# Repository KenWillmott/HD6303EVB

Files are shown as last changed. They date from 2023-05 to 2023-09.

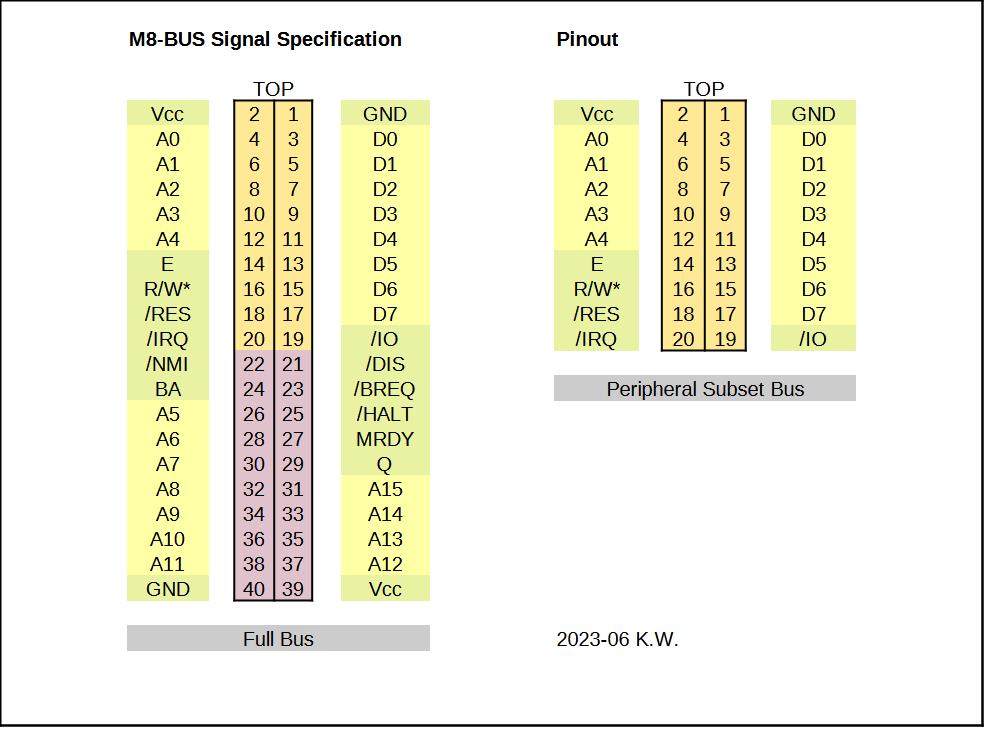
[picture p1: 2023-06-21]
expansion-pinout-final.jpg

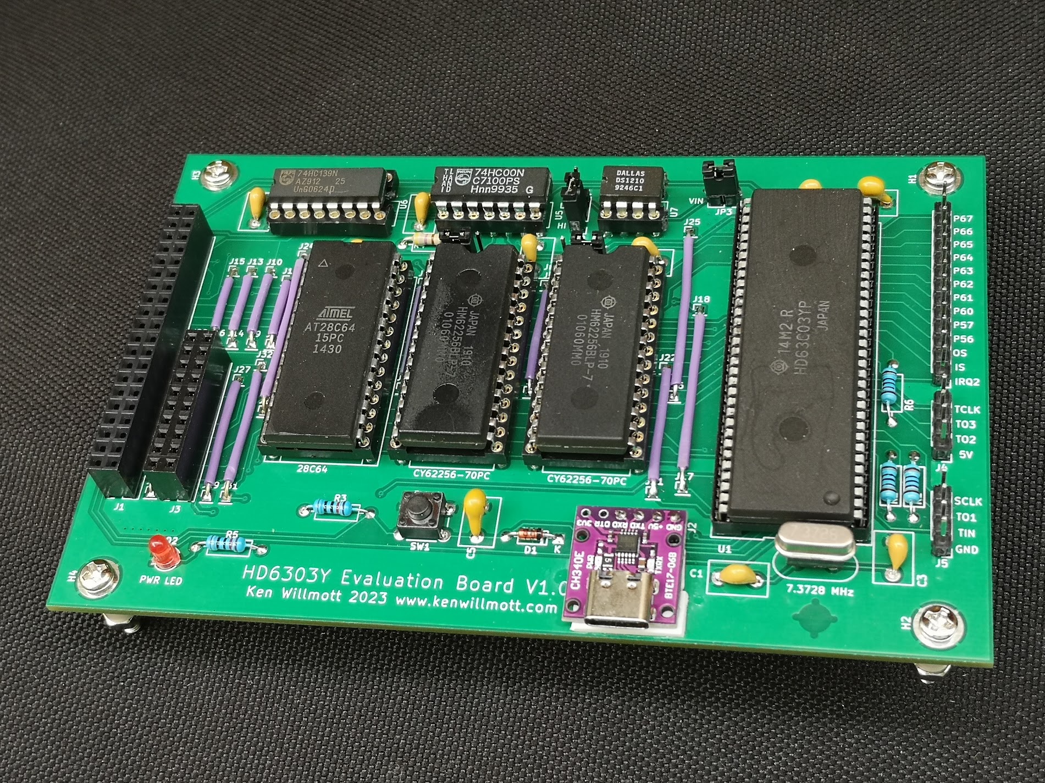
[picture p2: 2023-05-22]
HDEVB-SN002.jpg

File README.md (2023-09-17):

# HD6303EVB
# Hitachi HD63C03YP Evaluation Board

The HD63C03YP is a Hitachi MCU that combines a Motorola MC6803 code compatible processor, with on chip peripherals such as UART, parallel I/O, and hardware timers and counters. The MC6803 is code compatible with the MC6801, so development tools such as an assembler can be used to produce code for it. Also, existing software written for the MC6801/6803 should run on it, with few or no modifications.

The historical background is that Hitachi obtained a licence from Motorola to produce many of the devices in Motorola's 8 bit MCU catalog, which they implemented in an improved CMOS process. Many of the devices are pin compatible drop in replacements for the Motorola parts. But Hitachi also added new parts, and enhanced some of them with both documented and undocumented improvements.

The board consists of a 64 pin DIP HD63C03YP MCU, an 8k EEPROM, an external bus interface, I/O pins, and 64k SRAM. It can be interfaced from the on board serial port, running at 115200 baud and some slower baud rates. More hardware details can be found in the Wiki - https://github.com/KenWillmott/HD6303EVB/wiki.

The project is in the extreme beta stage, at the moment four working boards exist. The first and current board is designated V1.0. Some peripheral boards to plug into the expansion bus connectors, are in development. The Game Board is completed, see https://github.com/KenWillmott/M8-Game-Board/wiki

The provided ROM monitor program Kbug6303, can be written to the 8k EEPROM. Once it is installed, it is possible to perform firmware updates in place, by changing the write protect jumper on the board, and running software to copy the code from RAM to the EEPROM.

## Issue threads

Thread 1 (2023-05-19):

serial interface pin spacing

KenWillmott, 2023-05-19:
The pin header through holes are on 2mm centres and so don't align with the 2.54mm centres on a typical pin header. Fix in next revision.

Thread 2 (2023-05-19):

bus connector spacing

KenWillmott, 2023-05-19:
The spacing between adjacent bus connectors is too small. The right angle connectors that are planned for the peripheral cards require a wider gap. The dimension needs to be estimated.

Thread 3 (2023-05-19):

power supply connections

KenWillmott, 2023-05-19:
Currently the power comes from the USB-serial adapter. For more flexibility, a dedicated power supply connector and a jumper to select either it, or the USB power should be added.

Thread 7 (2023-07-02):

reset fan out

KenWillmott, 2023-07-02:
Several devices utilize the RESET line, connected to an RC circuit. This means devices come out of reset at different times because the inputs have different logic thresholds. It may be better to buffer the reset signal so that all devices are reset simultaneously.

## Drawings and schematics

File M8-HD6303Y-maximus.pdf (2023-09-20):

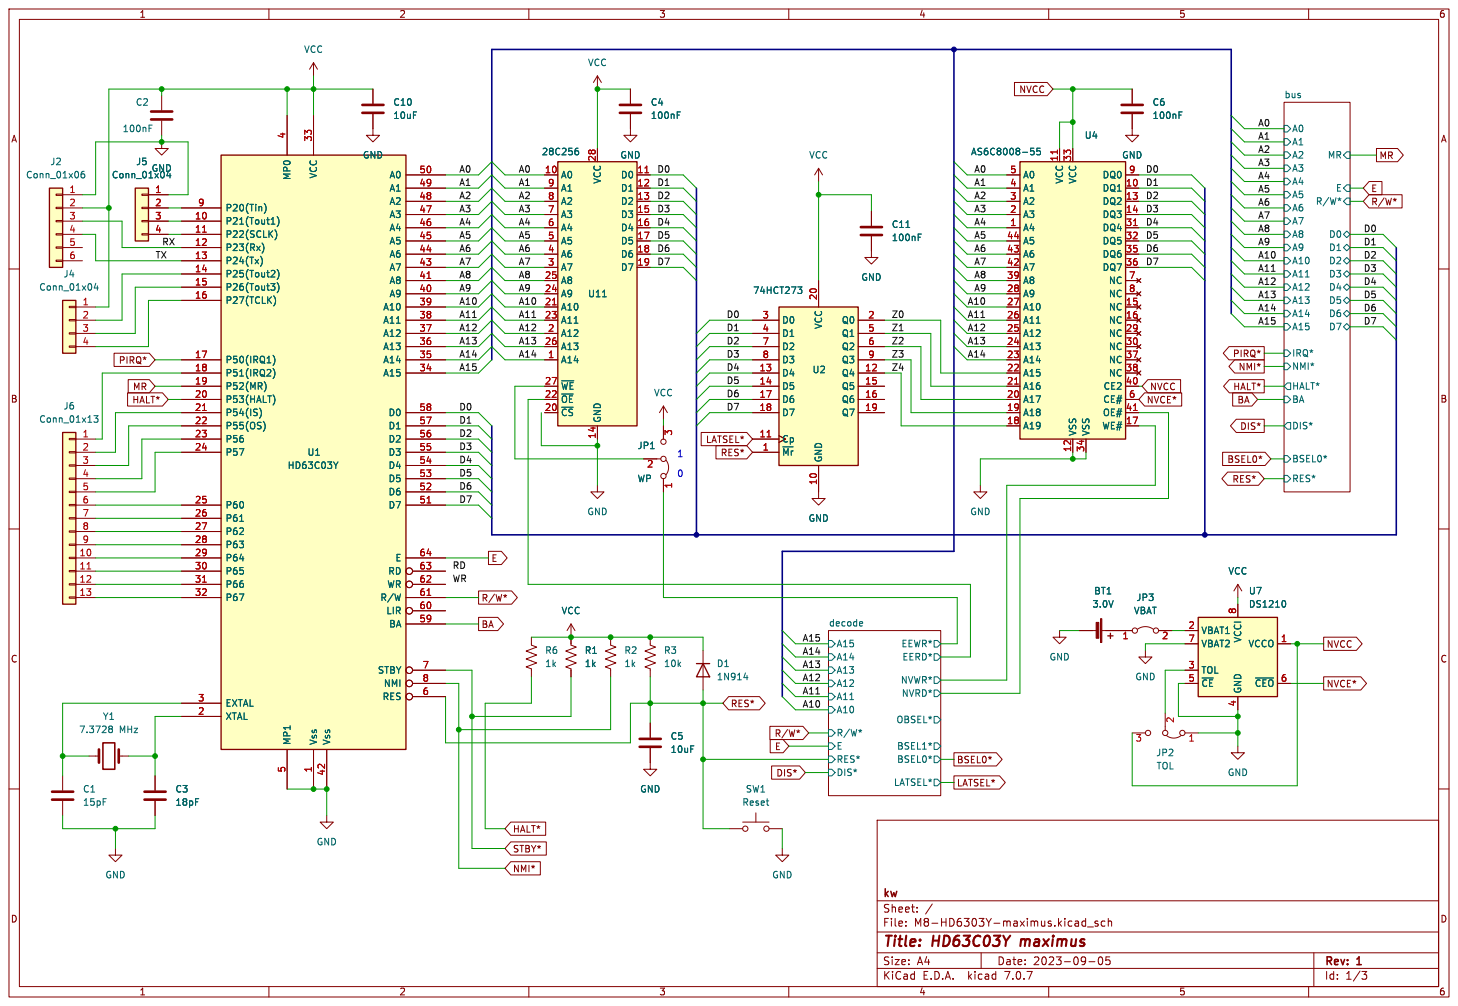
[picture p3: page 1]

File: M8-HD6303Y-maximus.kicad_sch Sheet: / kw

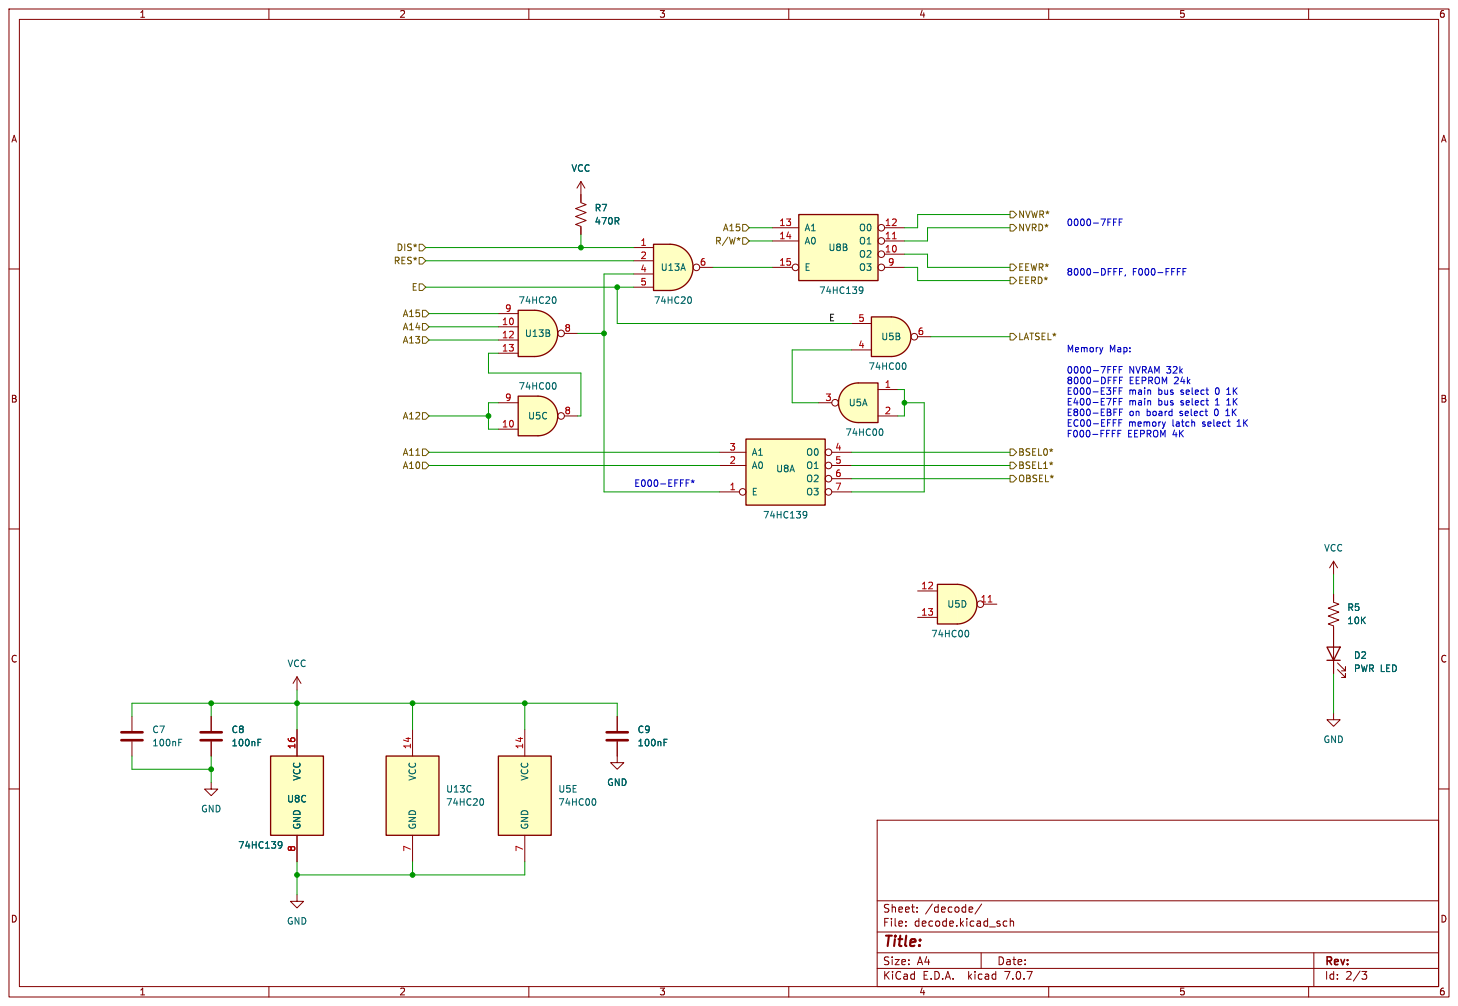
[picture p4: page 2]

Id: 2/3 Title: File: decode.kicad_sch Sheet: /decode/ VCC 14 GND

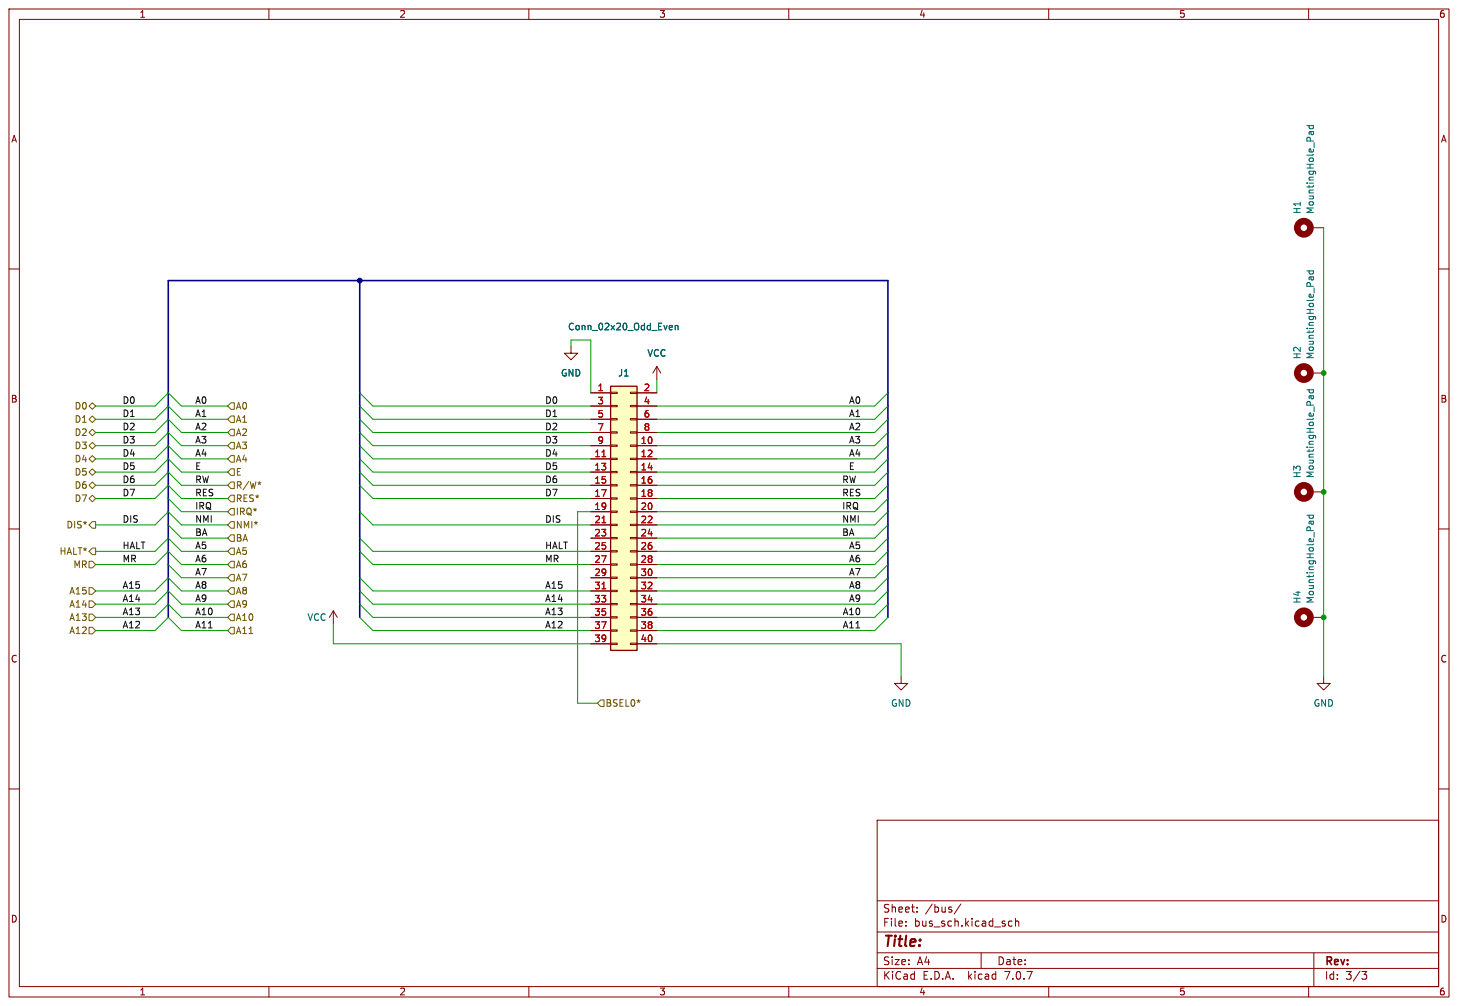
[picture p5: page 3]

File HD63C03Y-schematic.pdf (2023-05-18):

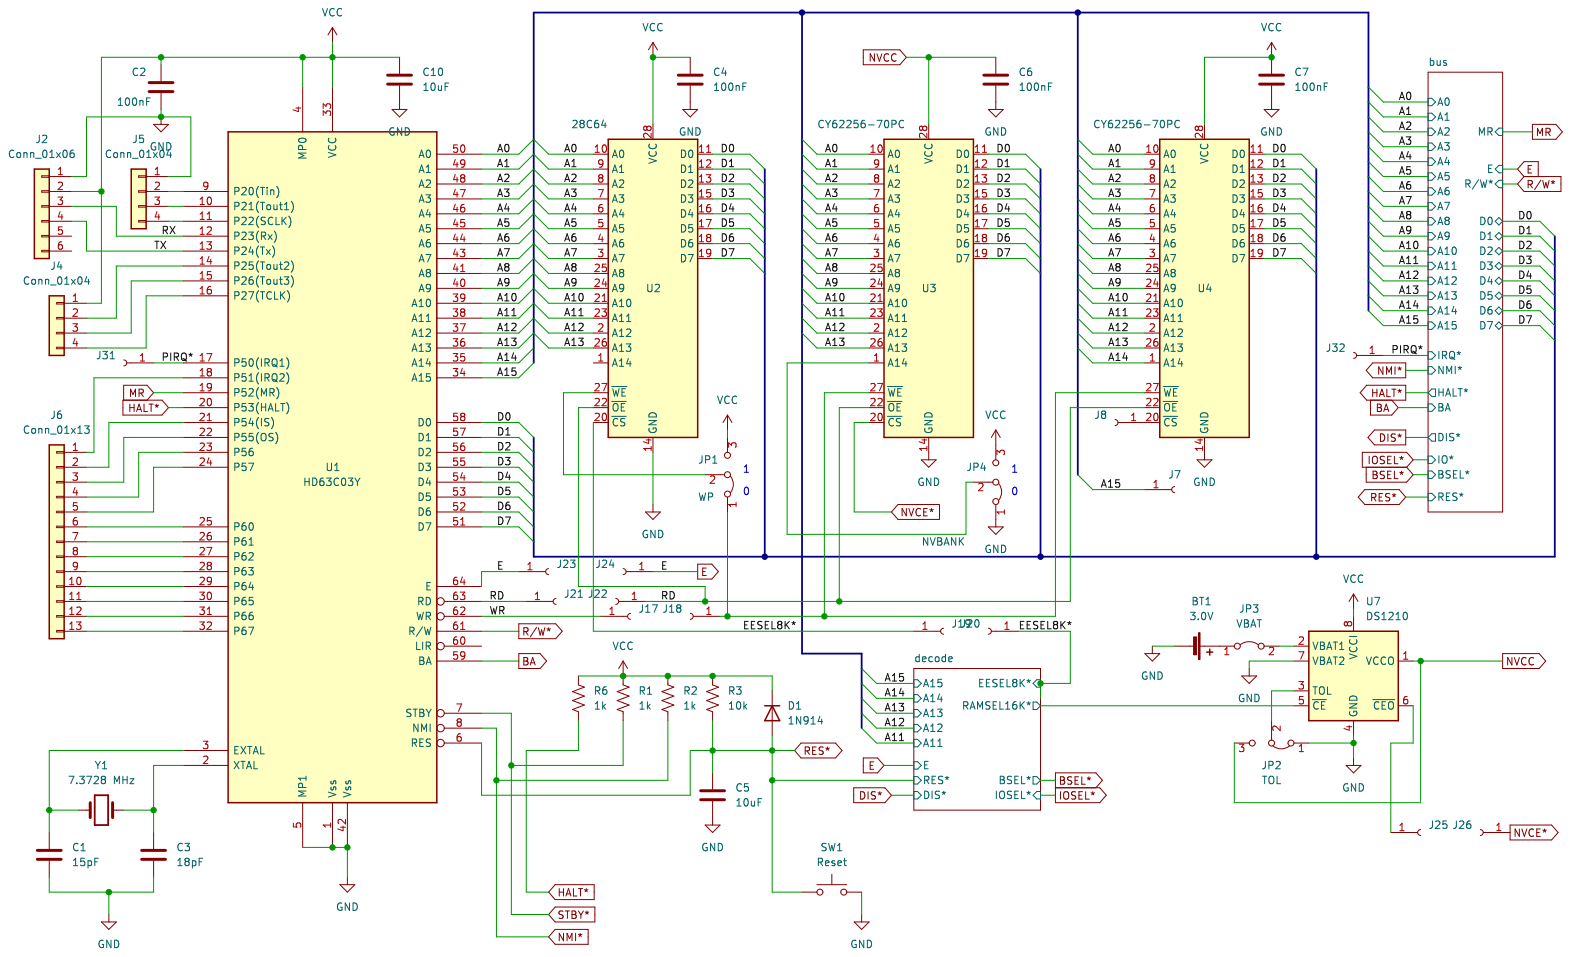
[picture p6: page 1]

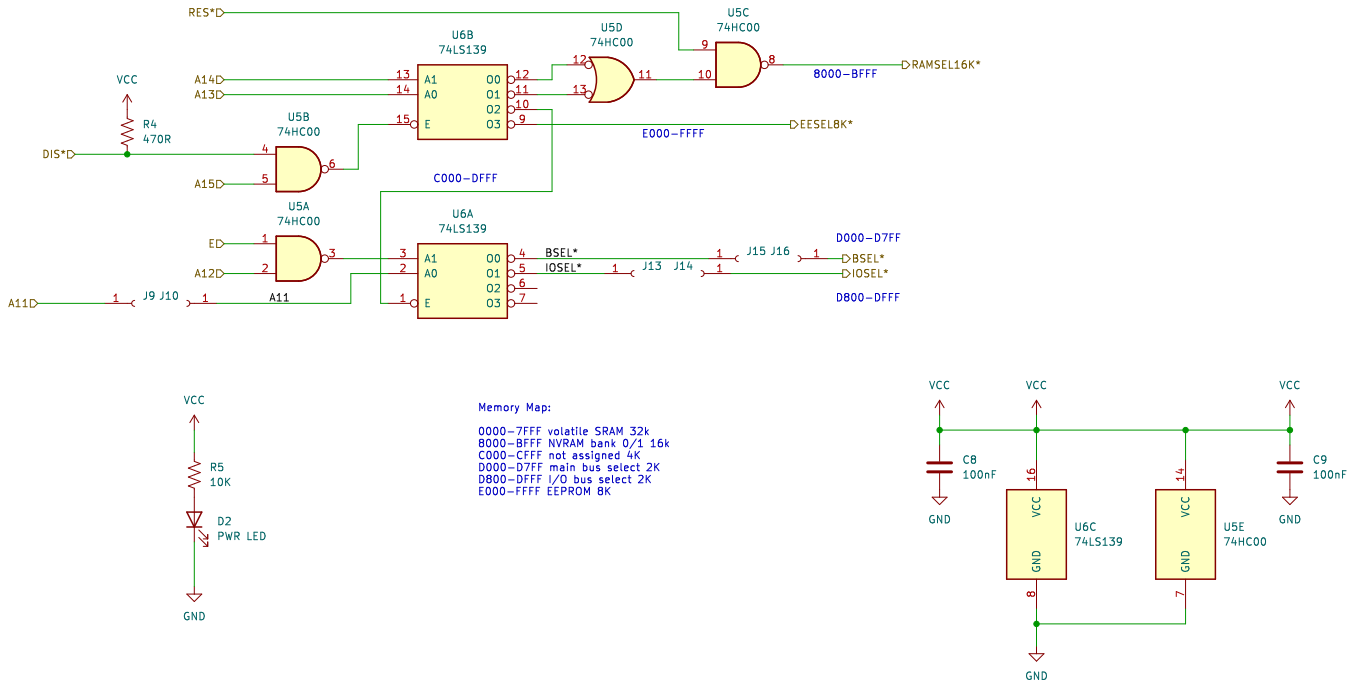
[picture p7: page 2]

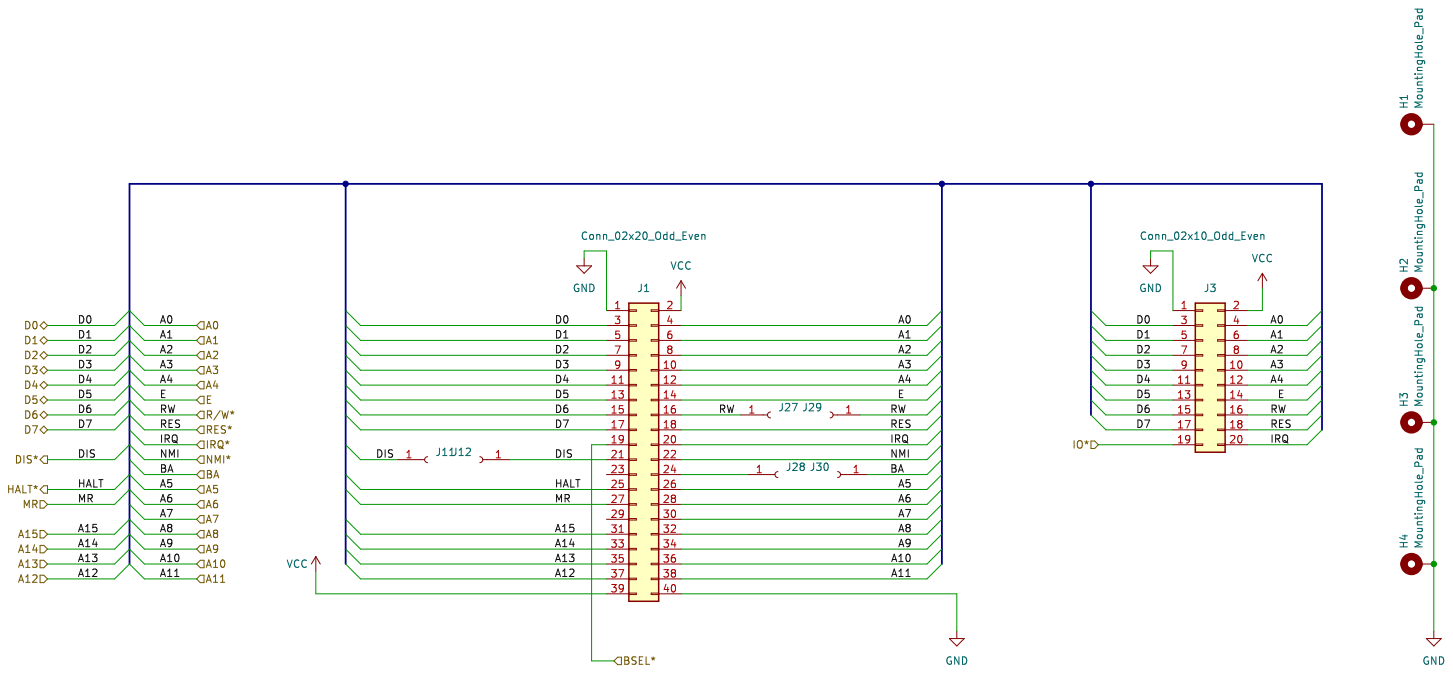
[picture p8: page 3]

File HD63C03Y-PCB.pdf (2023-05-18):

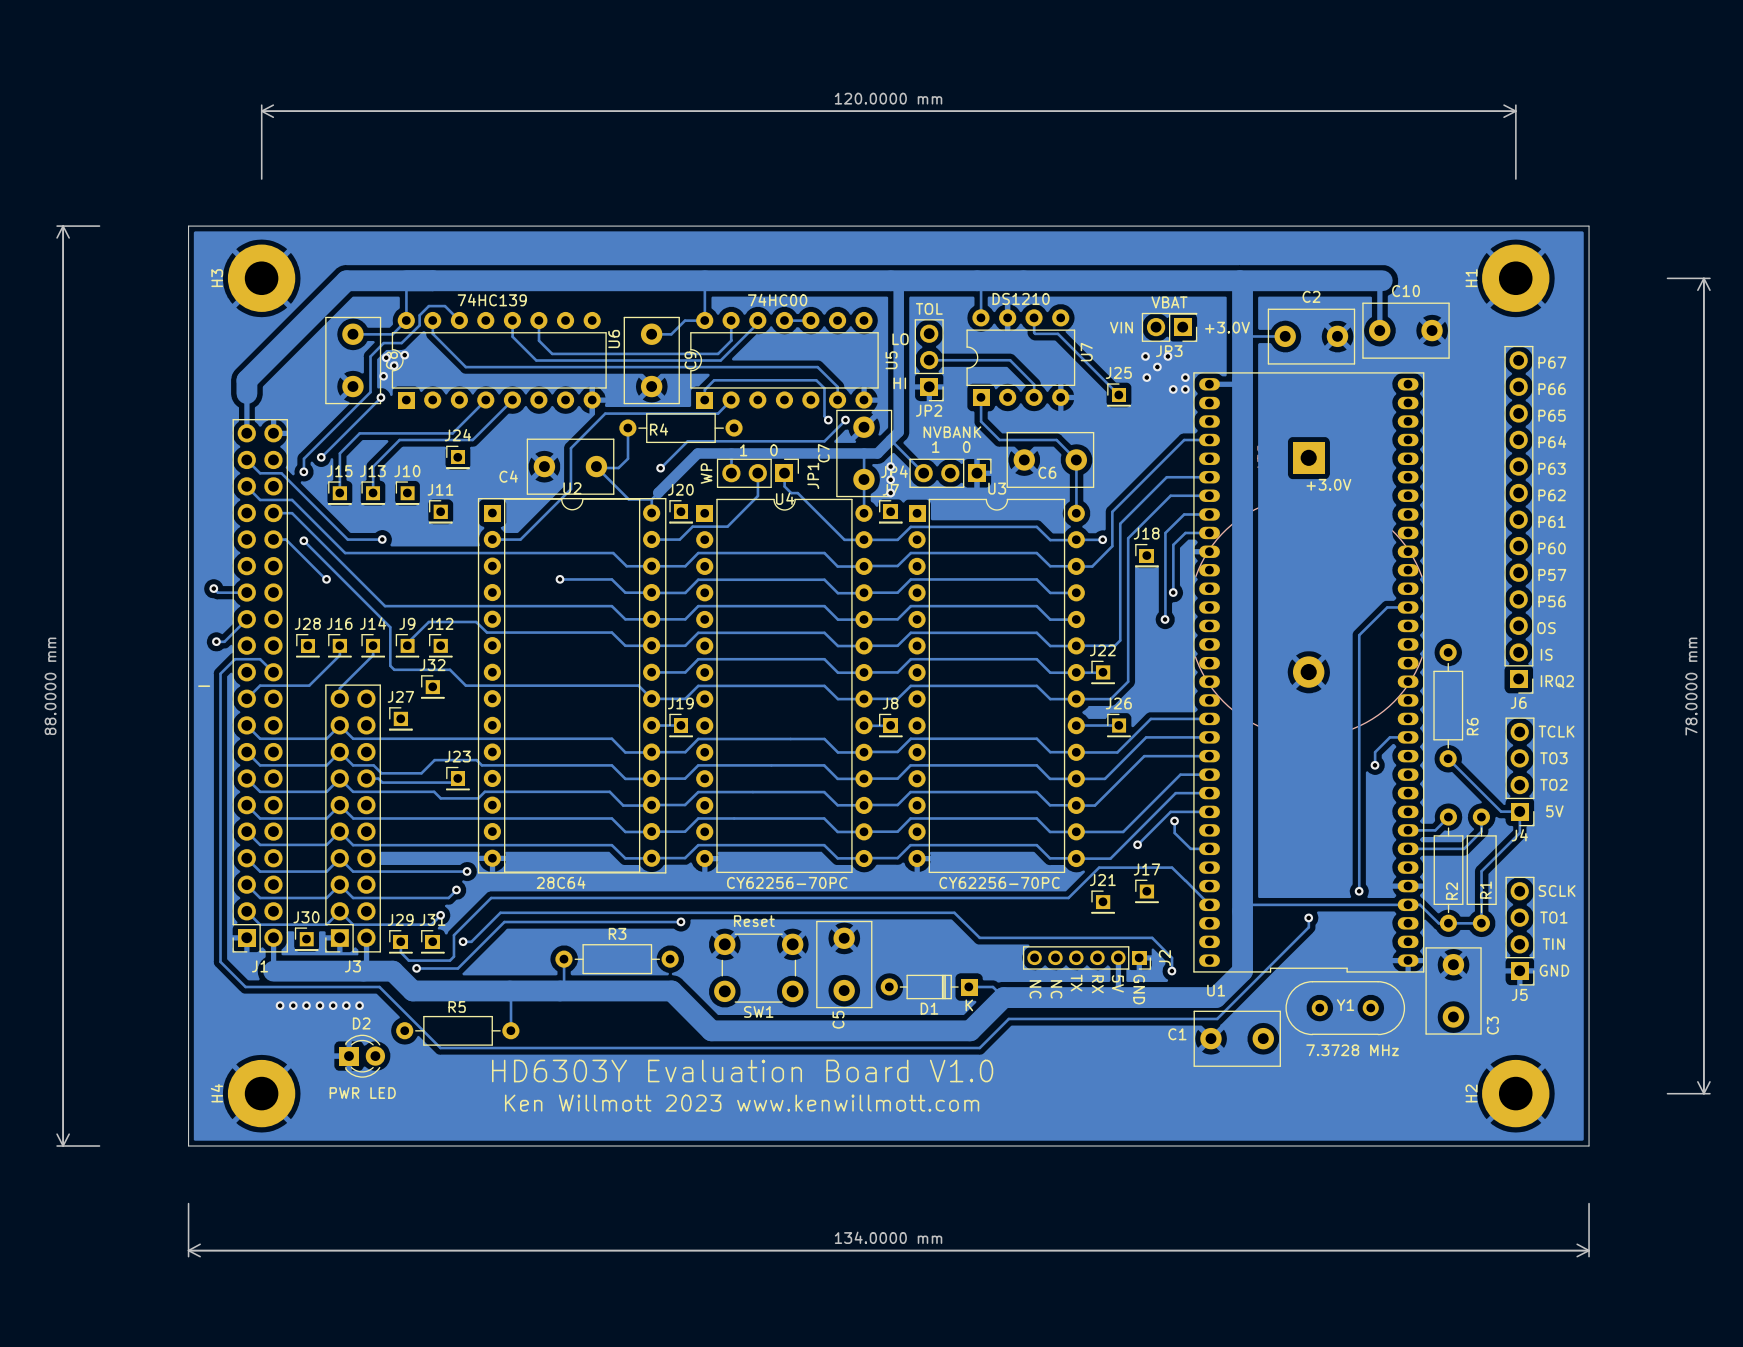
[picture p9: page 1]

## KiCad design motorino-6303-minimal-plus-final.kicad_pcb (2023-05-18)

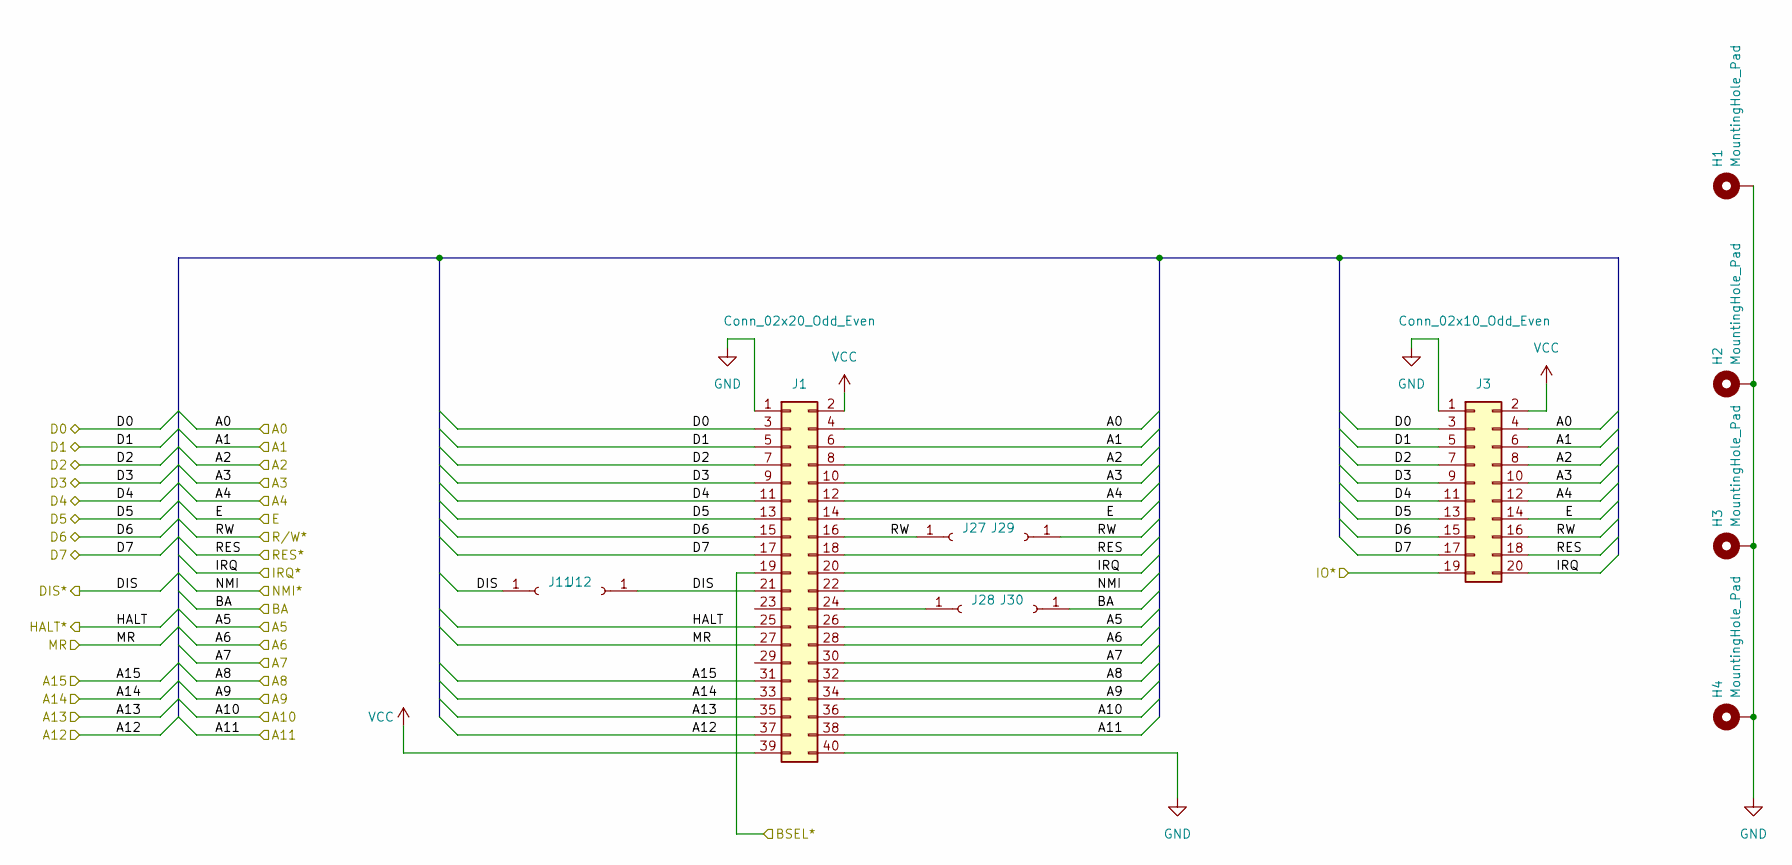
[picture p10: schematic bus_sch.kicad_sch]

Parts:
H1, H2, H3, H4: MountingHole_Pad; MountingHole_3.2mm_M3_Pad
J1: Conn_02x20_Odd_Even; PinSocket_2x20_P2.54mm_Vertical
J3: Conn_02x10_Odd_Even; PinSocket_2x10_P2.54mm_Vertical
J11, J12, J27, J28, J29, J30: Conn_01x01_Female; PinHeader_1x01_P2.00mm_Vertical

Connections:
/A0: J1.4, J3.4; also elsewhere on the board
/A1: J1.6, J3.6; also elsewhere on the board
/A2: J1.8, J3.8; also elsewhere on the board
/A3: J1.10, J3.10; also elsewhere on the board
/A4: J1.12, J3.12; also elsewhere on the board
/A5: J1.26; also elsewhere on the board
/A6: J1.28; also elsewhere on the board
/A7: J1.30; also elsewhere on the board
/A8: J1.32; also elsewhere on the board
/A9: J1.34; also elsewhere on the board
/A10: J1.36; also elsewhere on the board
/A11: J1.38; also elsewhere on the board
/A12: J1.37; also elsewhere on the board
/A13: J1.35; also elsewhere on the board
/A14: J1.33; also elsewhere on the board
/A15: J1.31; also elsewhere on the board
/D0: J1.3, J3.3; also elsewhere on the board
/D1: J1.5, J3.5; also elsewhere on the board
/D2: J1.7, J3.7; also elsewhere on the board
/D3: J1.9, J3.9; also elsewhere on the board
/D4: J1.11, J3.11; also elsewhere on the board
/D5: J1.13, J3.13; also elsewhere on the board
/D6: J1.15, J3.15; also elsewhere on the board
/D7: J1.17, J3.17; also elsewhere on the board
/PIRQ*: J1.20, J3.20; also elsewhere on the board
BA: J30.1; also elsewhere on the board
BSEL*: J1.19; also elsewhere on the board
DIS*: J1.21, J11.1, J12.1; also elsewhere on the board
E: J1.14, J3.14; also elsewhere on the board
GND: H1.1, H2.1, H3.1, H4.1, J1.1, J1.40, J3.1; also elsewhere on the board
HALT*: J1.25; also elsewhere on the board
IOSEL*: J3.19; also elsewhere on the board
MR: J1.27; also elsewhere on the board
NMI*: J1.22; also elsewhere on the board
unnamed: J1.24, J28.1
RES*: J1.18, J3.18; also elsewhere on the board
R/W*: J1.16, J3.16, J27.1, J29.1; also elsewhere on the board
VCC: J1.2, J1.39, J3.2; also elsewhere on the board

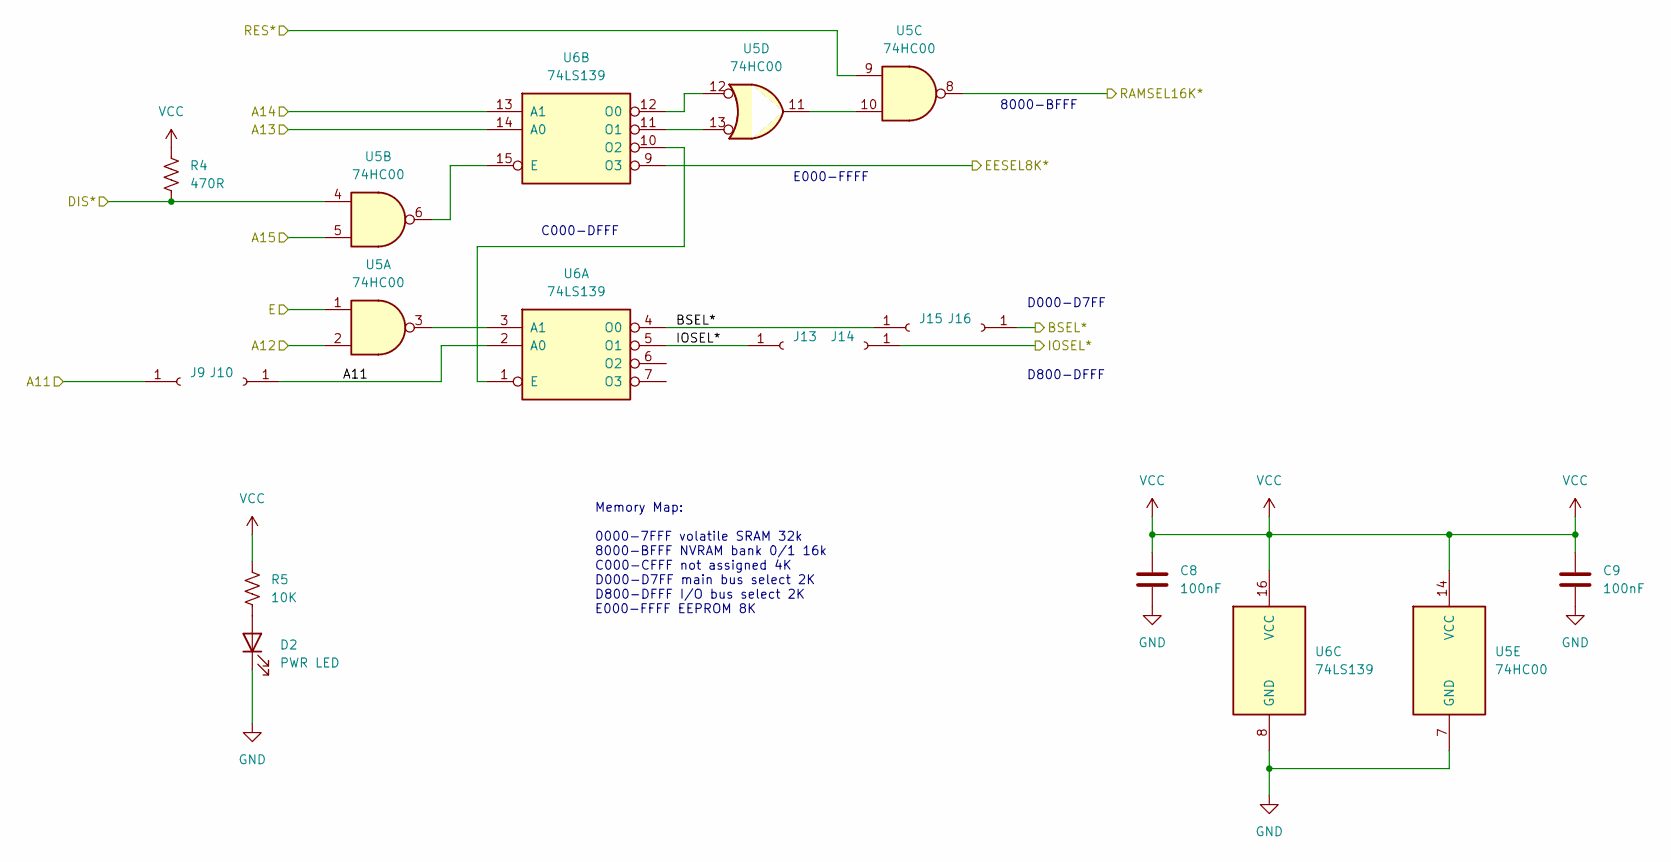
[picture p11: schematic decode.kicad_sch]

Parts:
C8, C9: 100nF; C_Disc_D8.0mm_W5.0mm_P5.00mm
D2: PWR LED; LED_D3.0mm
J9, J10, J13, J14, J15, J16: Conn_01x01_Female; PinHeader_1x01_P2.00mm_Vertical
R4: 470R; R_Axial_DIN0207_L6.3mm_D2.5mm_P10.16mm_Horizontal
R5: 10K; R_Axial_DIN0207_L6.3mm_D2.5mm_P10.16mm_Horizontal
U5: 74HC00; DIP-14_W7.62mm
U6: 74LS139; DIP-16_W7.62mm

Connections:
/A11: J9.1, J10.1, U6.2 (A0); also elsewhere on the board
/A12: U5.2; also elsewhere on the board
/A13: U6.14 (A0); also elsewhere on the board
/A14: U6.13 (A1); also elsewhere on the board
/A15: U5.5; also elsewhere on the board
/EESEL8K*: U6.9 (O3); also elsewhere on the board
/decode/RAMSEL16K*: U5.8; also elsewhere on the board
BSEL*: J15.1, J16.1, U6.4 (O0); also elsewhere on the board
DIS*: R4.2, U5.4; also elsewhere on the board
E: U5.1; also elsewhere on the board
GND: C8.2, C9.2, D2.1 (K), U5.7 (GND), U6.8 (GND); also elsewhere on the board
IOSEL*: J13.1, J14.1, U6.5 (O1); also elsewhere on the board
unnamed: D2.2 (A), R5.2
unnamed: U5.3, U6.3 (A1)
unnamed: U5.6, U6.15 (E)
unnamed: U5.10, U5.11
unnamed: U5.12, U6.12 (O0)
unnamed: U5.13, U6.11 (O1)
unnamed: U6.1 (E), U6.10 (O2)
RES*: U5.9; also elsewhere on the board
VCC: C8.1, C9.1, R4.1, R5.1, U5.14 (VCC), U6.16 (VCC); also elsewhere on the board

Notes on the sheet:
D800-DFFF
C000-DFFF
Memory Map: 0000-7FFF volatile SRAM 32k 8000-BFFF NVRAM bank 0/1 16k C000-CFFF not assigned 4K D000-D7FF main bus select 2K D800-DFFF I/O bus select 2K E000-FFFF EEPROM 8K
D000-D7FF
E000-FFFF
8000-BFFF

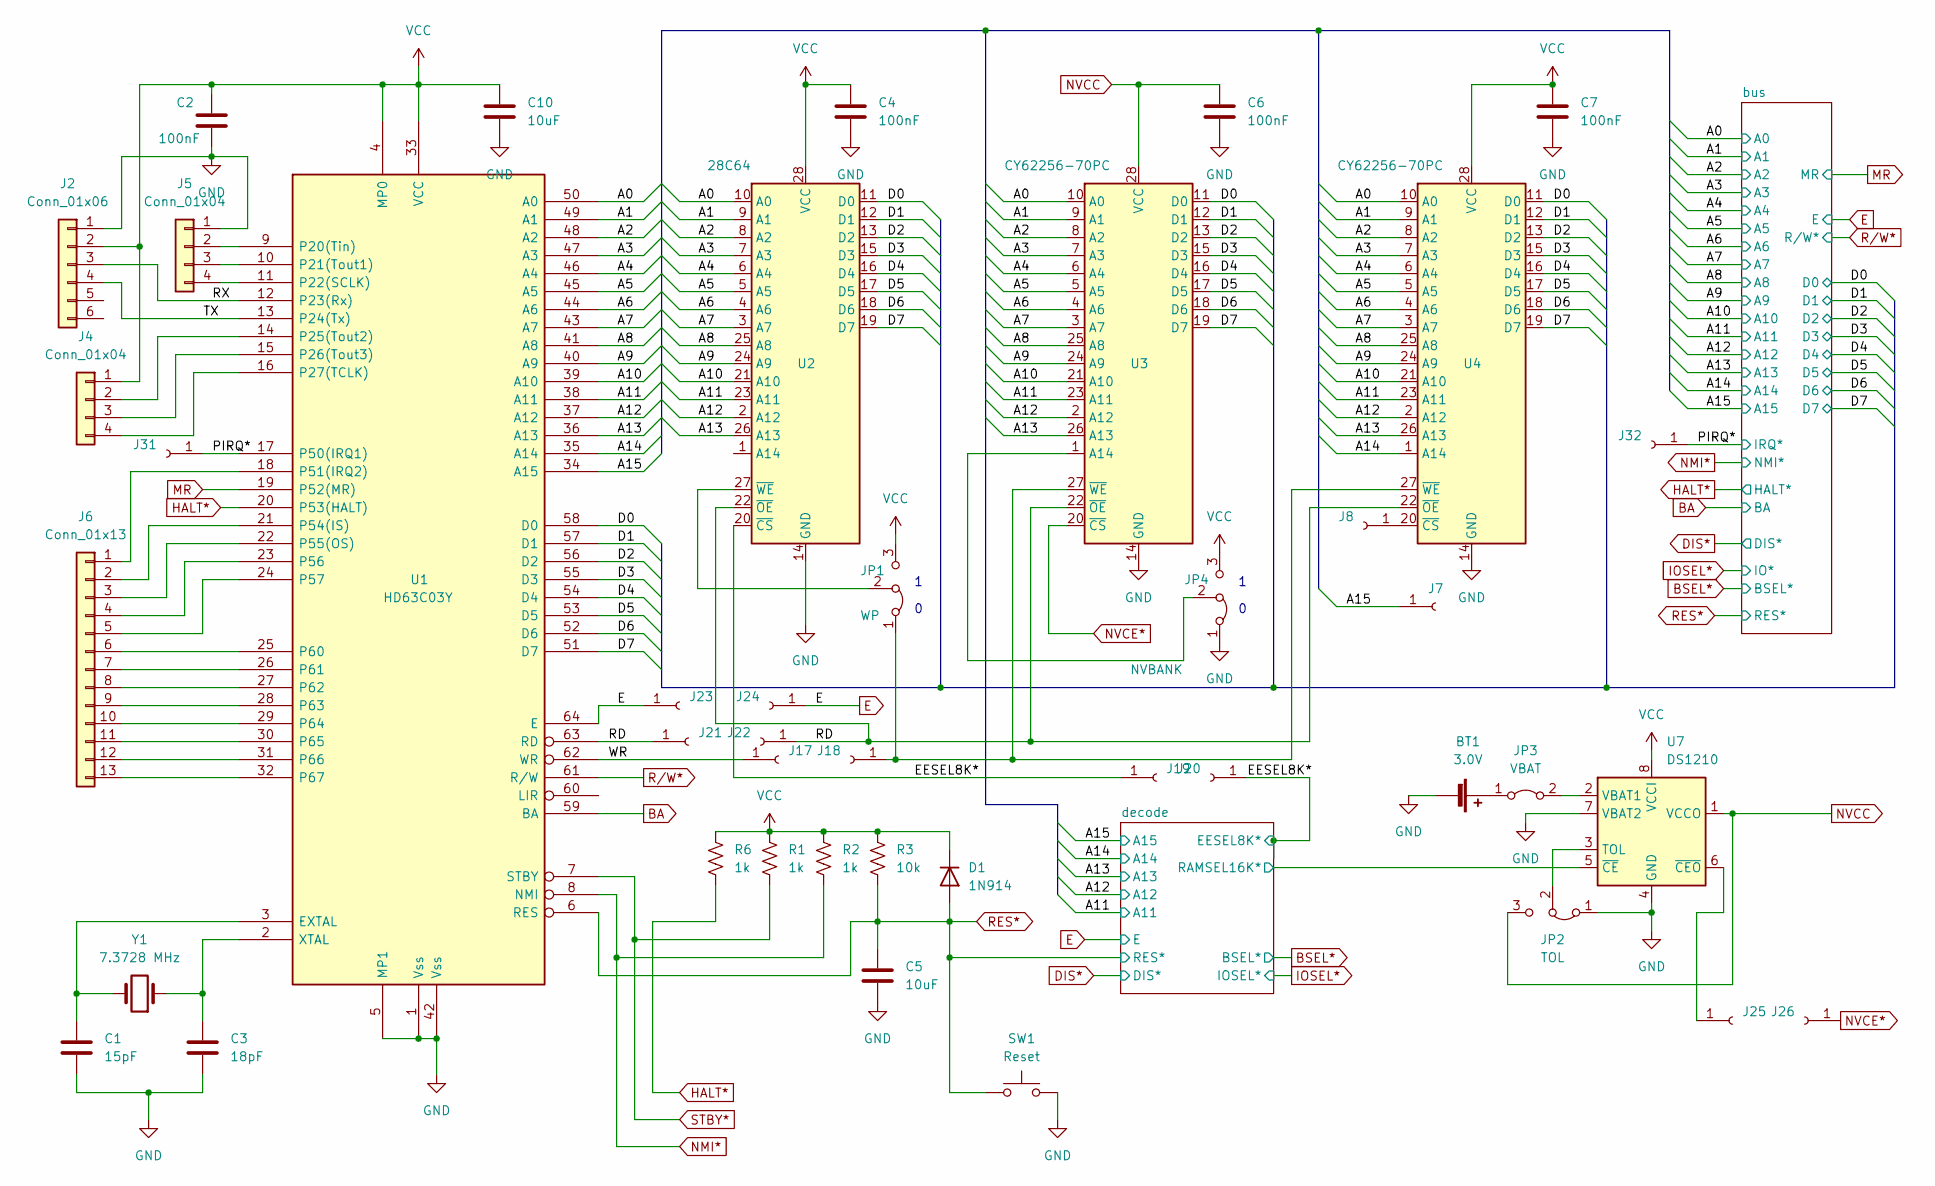
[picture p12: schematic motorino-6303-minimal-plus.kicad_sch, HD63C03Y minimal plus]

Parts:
BT1: 3.0V; BatteryHolder_Keystone_103_1x20mm
C1: 15pF; C_Disc_D8.0mm_W5.0mm_P5.00mm
C2, C4, C6, C7: 100nF; C_Disc_D8.0mm_W5.0mm_P5.00mm
C3: 18pF; C_Disc_D8.0mm_W5.0mm_P5.00mm
C5, C10: 10uF; C_Disc_D8.0mm_W5.0mm_P5.00mm
D1: 1N914; D_DO-35_SOD27_P7.62mm_Horizontal
J2: Conn_01x06; PinSocket_1x06_P2.00mm_Vertical
J4, J5: Conn_01x04; PinHeader_1x04_P2.54mm_Vertical
J6: Conn_01x13; PinHeader_1x13_P2.54mm_Vertical
J7, J8: (no value)
J17, J18, J19, J20, J21, J22, J23, J24, J25, J26, J31, J32: Conn_01x01_Female; PinHeader_1x01_P2.00mm_Vertical
JP1: WP; PinHeader_1x03_P2.54mm_Vertical
JP2: TOL; PinHeader_1x03_P2.54mm_Vertical
JP3: VBAT; PinHeader_2x01_P2.54mm_Vertical
JP4: NVBANK; PinHeader_1x03_P2.54mm_Vertical
R1, R2, R6: 1k; R_Axial_DIN0207_L6.3mm_D2.5mm_P10.16mm_Horizontal
R3: 10k; R_Axial_DIN0207_L6.3mm_D2.5mm_P10.16mm_Horizontal
SW1: Reset; SW_PUSH_6mm_H5mm
U1: HD63C03Y; DIP-64_HD63C03
U2: 28C64; DIP-28_W15.24mm_Socket
U3, U4: CY62256-70PC; DIP-28_W15.24mm
U7: DS1210; DIP-8_W7.62mm
Y1: 7.3728 MHz; Crystal_HC49-U_Vertical

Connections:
/A0: U1.50 (A0), U2.10 (A0), U3.10 (A0), U4.10 (A0); also elsewhere on the board
/A1: U1.49 (A1), U2.9 (A1), U3.9 (A1), U4.9 (A1); also elsewhere on the board
/A2: U1.48 (A2), U2.8 (A2), U3.8 (A2), U4.8 (A2); also elsewhere on the board
/A3: U1.47 (A3), U2.7 (A3), U3.7 (A3), U4.7 (A3); also elsewhere on the board
/A4: U1.46 (A4), U2.6 (A4), U3.6 (A4), U4.6 (A4); also elsewhere on the board
/A5: U1.45 (A5), U2.5 (A5), U3.5 (A5), U4.5 (A5); also elsewhere on the board
/A6: U1.44 (A6), U2.4 (A6), U3.4 (A6), U4.4 (A6); also elsewhere on the board
/A7: U1.43 (A7), U2.3 (A7), U3.3 (A7), U4.3 (A7); also elsewhere on the board
/A8: U1.41 (A8), U2.25 (A8), U3.25 (A8), U4.25 (A8); also elsewhere on the board
/A9: U1.40 (A9), U2.24 (A9), U3.24 (A9), U4.24 (A9); also elsewhere on the board
/A10: U1.39 (A10), U2.21 (A10), U3.21 (A10), U4.21 (A10); also elsewhere on the board
/A11: U1.38 (A11), U2.23 (A11), U3.23 (A11), U4.23 (A11); also elsewhere on the board
/A12: U1.37 (A12), U2.2 (A12), U3.2 (A12), U4.2 (A12); also elsewhere on the board
/A13: U1.36 (A13), U2.26 (A13), U3.26 (A13), U4.26 (A13); also elsewhere on the board
/A14: U1.35 (A14), U4.1 (A14); also elsewhere on the board
/A15: J7.1, U1.34 (A15); also elsewhere on the board
/D0: U1.58 (D0), U2.11 (D0), U3.11 (D0), U4.11 (D0); also elsewhere on the board
/D1: U1.57 (D1), U2.12 (D1), U3.12 (D1), U4.12 (D1); also elsewhere on the board
/D2: U1.56 (D2), U2.13 (D2), U3.13 (D2), U4.13 (D2); also elsewhere on the board
/D3: U1.55 (D3), U2.15 (D3), U3.15 (D3), U4.15 (D3); also elsewhere on the board
/D4: U1.54 (D4), U2.16 (D4), U3.16 (D4), U4.16 (D4); also elsewhere on the board
/D5: U1.53 (D5), U2.17 (D5), U3.17 (D5), U4.17 (D5); also elsewhere on the board
/D6: U1.52 (D6), U2.18 (D6), U3.18 (D6), U4.18 (D6); also elsewhere on the board
/D7: U1.51 (D7), U2.19 (D7), U3.19 (D7), U4.19 (D7); also elsewhere on the board
/EESEL8K*: J19.1, J20.1, U2.20 (~CS); also elsewhere on the board
/PIRQ*: J31.1, J32.1, U1.17 (P50(IRQ1)); also elsewhere on the board
/RD: J21.1, J22.1, U1.63 (RD), U2.22 (~OE), U3.22 (~OE), U4.22 (~OE)
/RX: J2.3, U1.12 (P23(Rx))
/TX: J2.4, U1.13 (P24(Tx))
/WR: J17.1, U1.62 (WR)
/decode/RAMSEL16K*: U7.5 (~CE); also elsewhere on the board
BA: U1.59 (BA); also elsewhere on the board
E: J23.1, J24.1, U1.64 (E); also elsewhere on the board
GND: BT1.2 (-), C1.2, C2.2, C3.2, C4.2, C5.2, C6.2, C7.2, C10.2, J2.1, J5.1, JP2.1 (A), JP4.1 (A), SW1.2, U1.1 (Vss), U1.5 (MP1), U1.42 (Vss), U2.14 (GND), U3.14 (GND), U4.14 (GND), U7.4 (GND), U7.7 (VBAT2); also elsewhere on the board
HALT*: R6.2, U1.20 (P53(HALT)); also elsewhere on the board
MR: U1.19 (P52(MR)); also elsewhere on the board
NMI*: R2.2, U1.8 (NMI); also elsewhere on the board
NVCC: C6.1, JP2.3 (B), U3.28 (VCC), U7.1 (VCCO)
NVCE*: J26.1, U3.20 (~CS)
unnamed: BT1.1 (+), JP3.1 (A)
unnamed: C1.1, U1.3 (EXTAL), Y1.2
unnamed: C3.1, U1.2 (XTAL), Y1.1
unnamed: J4.2, U1.14 (P25(Tout2))
unnamed: J4.3, U1.15 (P26(Tout3))
unnamed: J4.4, U1.16 (P27(TCLK))
unnamed: J5.2, U1.9 (P20(Tin))
unnamed: J5.3, U1.10 (P21(Tout1))
unnamed: J5.4, U1.11 (P22(SCLK))
unnamed: J6.1, U1.18 (P51(IRQ2))
unnamed: J6.2, U1.21 (P54(IS))
unnamed: J6.3, U1.22 (P55(OS))
unnamed: J6.4, U1.23 (P56)
unnamed: J6.5, U1.24 (P57)
unnamed: J6.6, U1.25 (P60)
unnamed: J6.7, U1.26 (P61)
unnamed: J6.8, U1.27 (P62)
unnamed: J6.9, U1.28 (P63)
unnamed: J6.10, U1.29 (P64)
unnamed: J6.11, U1.30 (P65)
unnamed: J6.12, U1.31 (P66)
unnamed: J6.13, U1.32 (P67)
unnamed: J8.1, U4.20 (~CS)
unnamed: J18.1, JP1.1 (A), U3.27 (~WE), U4.27 (~WE)
unnamed: JP1.2 (C), U2.27 (~WE)
unnamed: JP2.2 (C), U7.3 (TOL)
unnamed: JP3.2 (B), U7.2 (VBAT1)
unnamed: JP4.2 (C), U3.1 (A14)
unnamed: J25.1, U7.6 (~CEO)
RES*: C5.1, D1.2 (A), R3.2, SW1.1, U1.6 (RES); also elsewhere on the board
R/W*: U1.61 (R/W); also elsewhere on the board
STBY*: R1.2, U1.7 (STBY)
VCC: C2.1, C4.1, C7.1, C10.1, D1.1 (K), J2.2, J4.1, JP1.3 (B), JP4.3 (B), R1.1, R2.1, R3.1, R6.1, U1.4 (MP0), U1.33 (VCC), U2.28 (VCC), U4.28 (VCC), U7.8 (VCCI); also elsewhere on the board

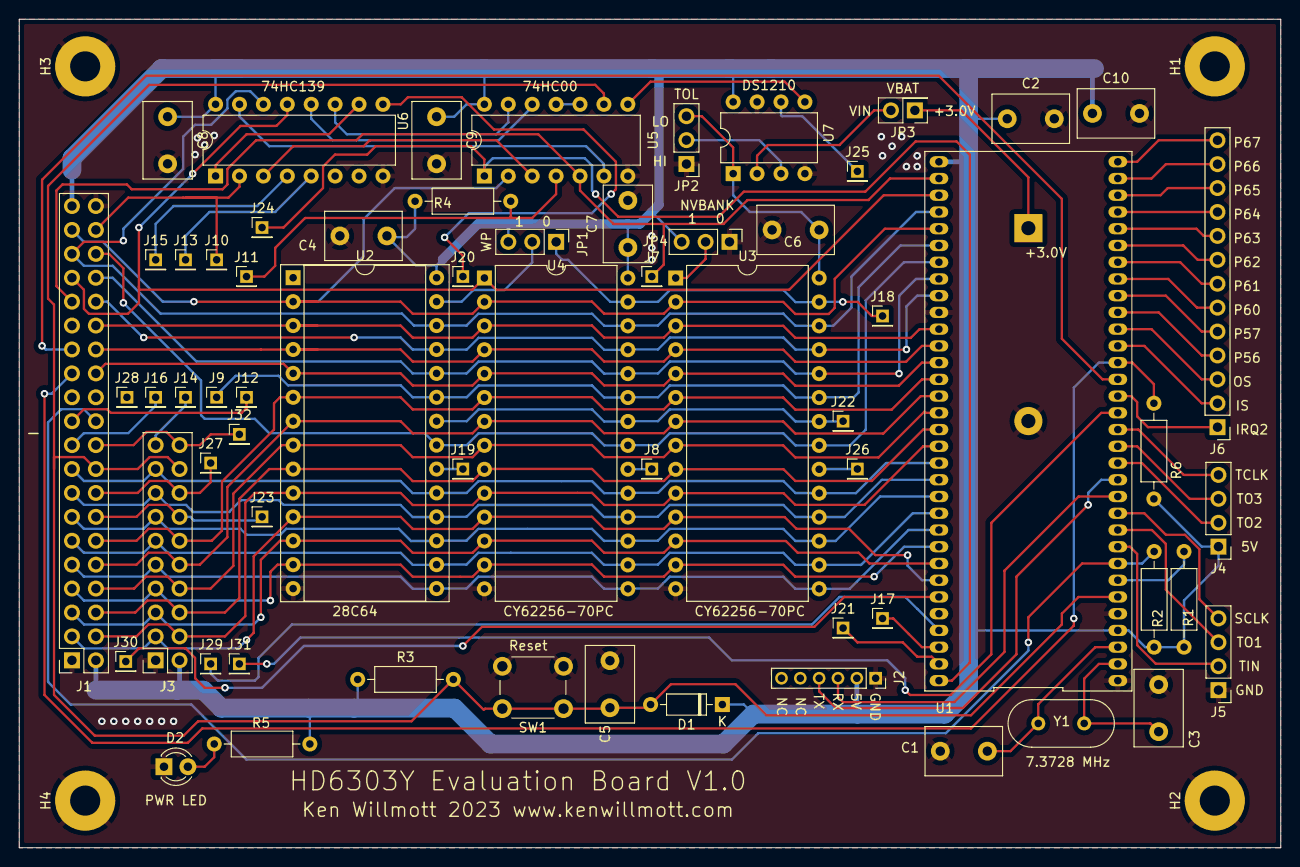
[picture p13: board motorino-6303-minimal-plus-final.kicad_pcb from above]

Board: 2 copper layers, 134.0 x 88.0 mm, 68 parts (1 on the bottom side), 83 nets.

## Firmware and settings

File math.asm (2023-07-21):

; math.asm
; routines from Hitachi
;
; 2023-07-17 transcribed K.W.
; 2023-07-21 convert to ASxxxx assembler syntax
;

	.hd6303
        .area   SYS (ABS,OVR)
	.org	0x8000

; Fill constant value p. 694
; Entry:
; ACCA (constant value)
; ACCB (byte count)
; X (start address)
;
; Return: none
;

FILL:	staa	0,x	;store constant
	inx		;increment address
	decb		;decrement counter
	bne	FILL	;loop while counter != 0
	rts

; Move memory blocks p. 698
; Entry:
; X (source address)
; DEA (dest address)
; ACCB (transfer count)
;
; Return: none
;

MOVE:	ldaa	0,x	;load transfer data
	inx		;increment source address
	pshx		;save source address
	ldx	DEA	;load dest address
	staa	0,x	;store transfer data
	inx		;increment dest address
	stx	DEA
	pulx		;restore source address
	decb		;decrement tranfer counter
	bne	MOVE	;loop while counter != 0
	rts

; Move strings p. 703
; Entry:
; X (source address)
; DEA (dest address)
;
; Return: none
;

MOVES:	ldaa	0,x	;Load transfer data
	beq	MOVS1	;branch to end if null found
	inx		;increment source address
	pshx		;save source address
	ldx	DEAS	;load destination address
	staa	0,x	;store transfer data
	inx		;increment dest address
	stx	DEAS	;save it
	pulx		;restore source address
	bra	MOVES
MOVS1:	rts

; Branching from a table p. 708
; Entry:
; ACCA (switch case value)
; X (table address)
;
; Return:
; X (table address)
; CCR C==1 found C==0 not found
;

CCASE:	tst	0,x	;command == 0
	beq	CCAS2	;branch to exit if null
	cmpa	0,x	;command same as command in table?
	beq	CCAS1	;branch if same
	inx
	inx
	inx		;increment table pointer
	bra	CCASE	;loop while not table end
CCAS1:	inx		;increment table pointer
	ldx	0,x	;load code module address
	sec		;load success code CCR C=1
CCAS2:	rts

; Make input case insensitive
; From p.718 Hitachi HD6301-3 Handbook
; Entry:
; ACCA (ASCII value)
;
; Return:
; ACCA (lower case value)
;

TPR:	cmpa	#'a
	bcs	TPR1
	cmpa	#'z
	bhi	TPR1
	anda	#0xDF	;Convert lowercase to uppercase
TPR1:	rts

; Convert ASCII hex to nibble p. 719
; Entry:
; ACCA (ASCII value)
;
; Return:
; ACCA (binary nibble)
; CCR C==1 invalid C==0 valid

NIBBLE:	suba	#'0
	bcs	NIB2	;if A >= 0 {
	adda	#0-'G+'0
	bcs	NIB2	;if A <= 0x0F {
	adda	#0xF+1-0xA
	bpl	NIB1	;if not A->F
	adda	#0xF+1-9
	bcs	NIB2	;if not 0->0xF
NIB1:	adda	#0x0A	;convert ASCII to binary
	clc		;clear carry
NIB2:	rts

; Convert byte to 2 ASCII characters p. 724
; Entry:
; ACCB (byte value)
;
; Return:
; ACCD (ASCII value)

COBYTE:	pshb		;save a copy of B
	
	lsrb
	lsrb
	lsrb
	lsrb		;upper 4 bits
	bsr	CONIB	;convert to ASCII
	tba		;place result in A

	pulb		;get saved copy
	andb	#0x0F	;mask
	bsr	CONIB	;convert to ASCII
	rts

CONIB:	addb	#'0
	cmpb	#'9
	bls	CONIB1		;if B <= 9 {
	addb	#'A-'9-1	;	}
CONIB1:	rts
	
; Count logical 1's in a byte p. 729
; Entry:
; ACCA (byte value)
;
; Return:
; ACCB (bit count)
	
HCNT:	ldx	#8	;load rotation count
	clrb		;clear count
HCNT1:	rola
	bcc	HCNT2	;if C==1 {
	incb		;}
HCNT2:	dex		;decrement count
	bne	HCNT1	;until count==0
	rola		;restore byte
	rts
	
; 32 bit shift right p. 733
; Entry:
; X (upper 16 bits)
; ACCD (lower 16 bits)
;
; Return:
; X (upper 16 bits)
; ACCD (lower 16 bits)

SHR32:	xgdx		;swap upper/lower
	lsrd		;shift upper
	xgdx		;swap
	rora
	rorb		;shift lower
	dec	SFCNTR	;decrement counter
	bne	SHR32	;until count==0
	rts

; 4 digit BCD counter p. 738
; Entry: none
;
; Return:
; DCNTR (2 byte BCD count value)
; CCR C==1 overflow C==0 no overflow

DECNT:	ldx	#2	;load addition counter
	sec		;init carry bit
DECNT1:	ldaa	#0	;clear A
	adca	DCNTR-1,x
	daa		;increment and convert to BCD
	staa	DCNTR-1,x	;store count
	dex		;until addition counter == 0
	bne	DECNT1
	rts

; 32 bit compare p. 743
; Entry:
; X (upper 16 bits)
; ACCD (lower 16 bits)
; CMT (32 bit number to compare)

; Return:
; CCR C & Z

CMP32:	cpx	CMT	;compare x with CMT+3, CMT+2
	bne	CMP1	;if .equal {
	xgdx		;swap X/ACCD
	cpx	CMT+2	;compare x with CMT+1, CMT
	xgdx		;swap X/ACCD
CMP1:	rts

; 32 bit addition p. 749
; Entry:
; X (upper 16 bits)
; ACCD (lower 16 bits)
; ADER (32 bit number to add)

; Return:
; X (upper 16 bits result)
; ACCD (lower 16 bits result)
; CCR C==1 overflow C==0 no overflow

ADD32:	addd	ADER+2
	xgdx		;swap X/ACCD
	adcb	ADER+1
	adca	ADER
	xgdx		;swap X/ACCD
	rts
	
; 32 bit subtraction p. 755
; Entry:
; X (upper 16 bits)
; ACCD (lower 16 bits)
; SBER (32 bit number to subtract)

; Return:
; X (upper 16 bits result)
; ACCD (lower 16 bits result)
; CCR C==1 borrow C==0 no

SUB32:	subd	SBER+2
	xgdx		;swap X/ACCD
	sbcb	SBER+1
	sbca	SBER
	xgdx		;swap X/ACCD
	rts

; 16 bit multiplication p. 761
; Entry:
; X (upper 16 bits)
; ACCD (lower 16 bits)
; SBER (32 bit number to subtract)

; Return:
; X (upper 16 bits result)
; ACCD (lower 16 bits result)
; CCR C==1 borrow C==0 no

MUL16:	clra
	clrb	
	std	PRDCT	;clear product area
	ldaa	MCAND+1
	ldab	MER+1
	mul
	std	PRDCT+2
	ldaa	MCAND
	ldab	MER+1
	mul
	addd	PRDCT+1
	std	PRDCT+1
	ldaa	MCAND+1
	ldab	MER
	mul
	addd	PRDCT+1
	std	PRDCT+1
	rol	PRDCT	;handle carry out
	ldaa	MCAND
	ldab	MER
	mul
	addd	PRDCT
	std	PRDCT
	rts

; 16 bit division p. 768
; Entry:
; X (dividend)
; DVS (divisor)

; Return:
; X (upper 16 bits result)
; ACCD (quotient)
; X (remainder)

DIV16:	ldaa	#16
	staa	DICNTR	;init shift counter
	clra
	clrb
DIV1:	xgdx		;swap X/ACCD
	asld
	xgdx		;swap X/ACCD
	rolb
	rola
	subd	DVS
	inx
	bcc	DIV2
	addd	DVS
	dex
DIV2:	dec	DICNTR
	bne	DIV1
	rts

; 8 digit packed BCD addition p. 774
; Entry:
; ABD (augend)
; ACD (addend)

; Return:
; ABD (augend)
; CCR C==1 overflow C==0 no overflow

ADDBCD:	ldx	#4	;init addition counter
	clc
ADDD1:	ldaa	ABD-1,x
	adca	ABD-1,x	;augend + addend
	daa		;decimal adjust
	staa	ABD-1,x
	dex
	bne	ADDD1
	rts

; 8 digit packed BCD subtraction p. 780
; Entry:
; SUBEDS (minuend)
; SUBERS (subtrahend)

; Return:
; SUBEDS (remainder)
; CCR C==1 true, C==0 borrow

SUBBCD:	ldx	#4		;init addition counter
SUBD1:	ldd	#0x9999
	subd	SUBERS-2,x
	std	SUBERS-2,x
	dex
	dex
	bne	SUBD1
	
	sec
	ldx	#4		;init addition counter
SUBD2:	ldaa	SUBEDS-1,x
	adca	SUBERS-1,x
	daa			;decimal adjust
	staa	SUBEDS-1,x
	dex
	bne	SUBD2
	rts

; 16 bit square root p. 786
; Entry:
; X (integer)

; Return:
; SANS (remainder)

SQRT16:	ldaa	#8
	staa	SCNTR	;initialize shift counter
	clra
	clrb		;D = 0
	std	SANS	;SANS = 0
	xgdx		;swap X/ACCD
SQRT1:	asld		;Rotate upper 2 bits of X to low 2 of ACCD
	xgdx		;swap X/ACCD
	rolb
	rola
	xgdx		;swap X/ACCD
	asld
	xgdx		;swap X/ACCD
	rolb
	rola
	
	sec		;set LSB of SANS
	rol	SANS+1
	rol	SANS
	subd	SANS	;D = D - SANS
	bcs	SQRT3	;branch if minus
	inc	SANS+1	;++SANS
SQRT2:	dec	SCNTR	;decrement shift counter
	xgdx		;swap X/ACCD
	bne	SQRT1
	asr	SANS	;SANS = SANS / 2
	ror	SANS+1
	rts
	
SQRT3:	addd	SANS
	dec	SANS+1	;SANS = SANS - 1
	bra	SQRT2

; 16 bit binary to 5 digit BCD p. 791
; Entry:
; HEXD (16 bit integer)

; Return:
; DECD (5 digit packed BCD in 3 bytes)
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

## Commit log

2023-05-22 Completed board image
2023-07-19 Monitor Firmware - v. 1.03
    This version is ported from the Motorola standard assembler, to the ASxxxx macro assembler by Alan Baldwin. All my development will use it from now on, if only because it supports the HD6303 extra in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
2023-07-21 PCF8584 interface code NON WORKING!!!!
    Motorola assembler format.
2023-07-21 Hitachi math code - ASX assembler version
2023-09-20 Next generation HD6303Y board schematic
    Might be split into separate boards, but this logic will remain.
